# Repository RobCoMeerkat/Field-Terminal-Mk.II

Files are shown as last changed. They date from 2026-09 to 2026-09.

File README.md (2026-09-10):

# RobCo Field Terminal MkII

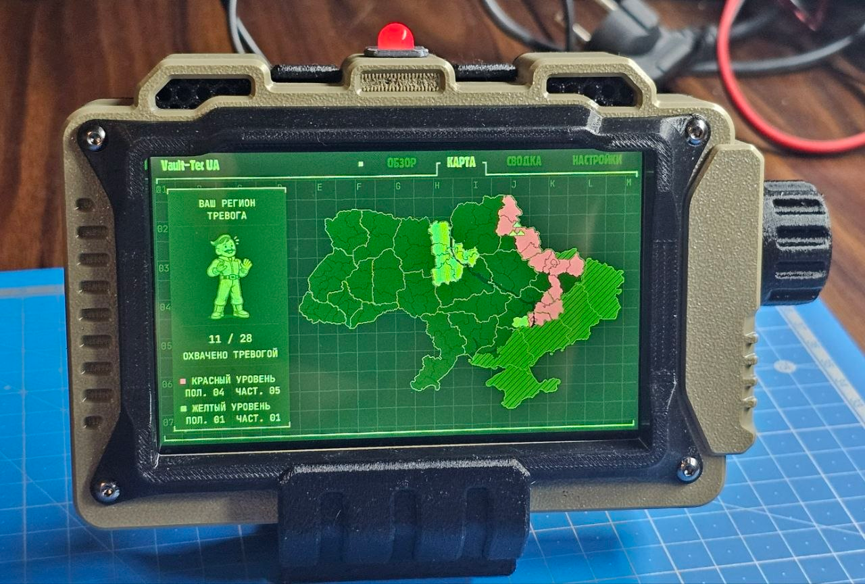
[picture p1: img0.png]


> [!NOTE]
>
> * **Происхождение проекта:** Изначально "терминал" задумывался как настольное устройство с условно полезным функционалом. Т.е. формально игрушка для рабочего стола сделанная на коленке из того что было, ничего серьезного. Проект разрабатывался исключительно для личного использования и был ориентирован на мои собственные потребности.
> * **Доступность сервера:** Серверная часть проекта поддерживается за счёт личных средств. Сервер будет поддерживаться максимально долго по мере возможности, однако в текущих реалиях **гарантии стабильной работы и доступности сервера не предоставляется**.
> * **Точность данных и возможные сбои:** Система использует сторонние API и внешние источники данных, получение информации из которых в отдельных случаях реализовано нестандартными способами(т.е. костылями). Поэтому возможны задержки, временная недоступность отдельных функций и ошибки, не зависящие от меня. **Ответственность за актуальность, точность и своевременность отображаемой информации на себя не беру.**
> * **Обратная связь:** Сообщения об ошибках, конструктивные предложения и идеи по улучшению проекта приветствуются.

---

## 1. Необходимые компоненты

### Электроника

* Отладочная плата **ESP32-8048S050C** в сенсорном исполнении, с экраном 5 дюймов, разрешение 800×480.
  ([Заказывал здесь](https://www.aliexpress.com/item/1005006625220768.html))
* Модуль энкодера **KY-040 (EC11 с резьбой)** — стандартный модуль с пятью выводами: CLK, DT, SW, + и GND.
  ([Пример используемого модуля](https://arduino.ua/ru/prod1223-modyl-enkoder))
* Разъём **USB Type-C "мама"**.
  ([Пример используемого разъёма](https://www.aliexpress.com/item/1005006099544502.html))
* Красный светодиод 8 мм для индикации тревоги.
* Резистор **330 Ом**.
* Соединительные провода и коннекторы.
* USB-кабель для подключения платы к компьютеру (поставляется в комплекте с платой).

### Крепёж и детали корпуса

* Винты M3х24 мм с гайками — 4 шт.
* Винты M2х8 мм с гайками — 2 шт.
* Резиновые кольца или прокладки — 4 шт.
* Детали корпуса, напечатанные на 3D-принтере из PETG пластика.

### Программное обеспечение и драйвер

* [Драйвер USB-SERIAL CH340](https://www.wch-ic.com/downloads/CH341SER_EXE.html)
* [esptool v5.4.0](https://github.com/espressif/esptool/releases/download/v5.4.0/esptool-v5.4.0-windows-amd64.zip)

### Дополнительно

* Немного суперклея.

---

## 2. Первая прошивка

### 2.1. Подготовка

1. Установить драйвер **CH340** и перезагрузить компьютер.
2. Создать в корне диска, например `C:`, отдельную папку для прошивки. Для примера будем использовать:

   ```text
   C:\esptool
   ```
3. Распаковать скачанный архив **esptool** в созданную папку.
4. [Скачайть готовую прошивку](https://github.com/RobCoMeerkat/Field-Terminal-Mk.II/releases/download/test/RobCoFieldTerminal_MkII_V1.5.0_FULL_FACTORY_16MB.bin) и поместить файл `.bin` в ту же папку, рядом с `esptool.exe`.
5. Подключить плату к компьютеру через **USB-порт непосредственно на самой плате**.

---

### 2.2. Определение COM-порта

1. Открыть командную строку Windows:

   * нажать **Win + R**;
   * ввести `cmd`;
   * нажать **Enter**.

2. Перейти в папку, где находятся `esptool.exe` и файл прошивки:

   ```cmd
   cd C:\esptool
   ```

   Если использовали другое расположение папки, указать соответствующий путь.

3. Выполнить команду:

   ```cmd
   esptool flash-id
   ```

4. Дождаться появления информации об обнаруженном устройстве. Найти строку вида:

   ```text
   Connected to ESP32-S3 on COM9
   ```

   В моем случае устройство находится на порту **COM9**.

   **Запомнить номер COM-порта.** В дальнейшем вместо `COM9` необходимо использовать порт, который определился именно на вашем компьютере.

---

### 2.3. Очистка памяти

Перед первой прошивкой рекомендуется полностью удалить заводскую прошивку и содержимое памяти.

Выполнить команду, заменив `COM9` на свой COM-порт:

```cmd
esptool --chip esp32s3 --port COM9 erase-flash
```

Дождаться завершения операции.

При успешном выполнении в конце должен появиться результат примерно следующего вида:

```text
Flash memory erased successfully in XX seconds.
```

---

### 2.4. Прошивка устройства

После очистки памяти можно записать новую прошивку.

Выполнить команду, заменив:

* `COM9` — на COM-порт вашего устройства;
* `RobCoFieldTerminal_MkII_V1.5.0_FULL_FACTORY_16MB.bin` — на фактическое имя файла прошивки, если оно отличается.

```cmd
esptool --chip esp32s3 --port COM9 --baud 230400 write-flash 0x0 RobCoFieldTerminal_MkII_V1.5.0_FULL_FACTORY_16MB.bin
```

Дождаться полного завершения процесса.

Если прошивка выполнена успешно, устройство автоматически запустится.

---

## 3. Первоначальная настройка

После запуска дождитесь появления **QR-кода на экране терминала**.

1. Отсканируйте QR-код телефоном.

2. Подключитесь к Wi-Fi сети, которую создаёт терминал.

3. Откройте в браузере адрес:

   ```text
   192.168.4.1
   ```

4. Откроется веб-панель терминала(нужно подождать, может долго грузиться).

5. Выполните первоначальную настройку устройства.

6. Можно отключаться от компьютера и переходить к сборке.

---

## 4. Сборка

### 4.1. Подключение светодиода:
```
IO17 → резистор 330 Ом → анод LED
GND  → катод LED
```

### 4.2. Подключение энкодера:
```
CLK → IO11
DT  → IO12
SW  → IO13
+   → 3.3V
GND → GND
```

### 4.3. Подключение заднего USB порта:
```
+ (Красный) → 5V
GND(Черный) → GND
```
#### Пример колхозного подключения:
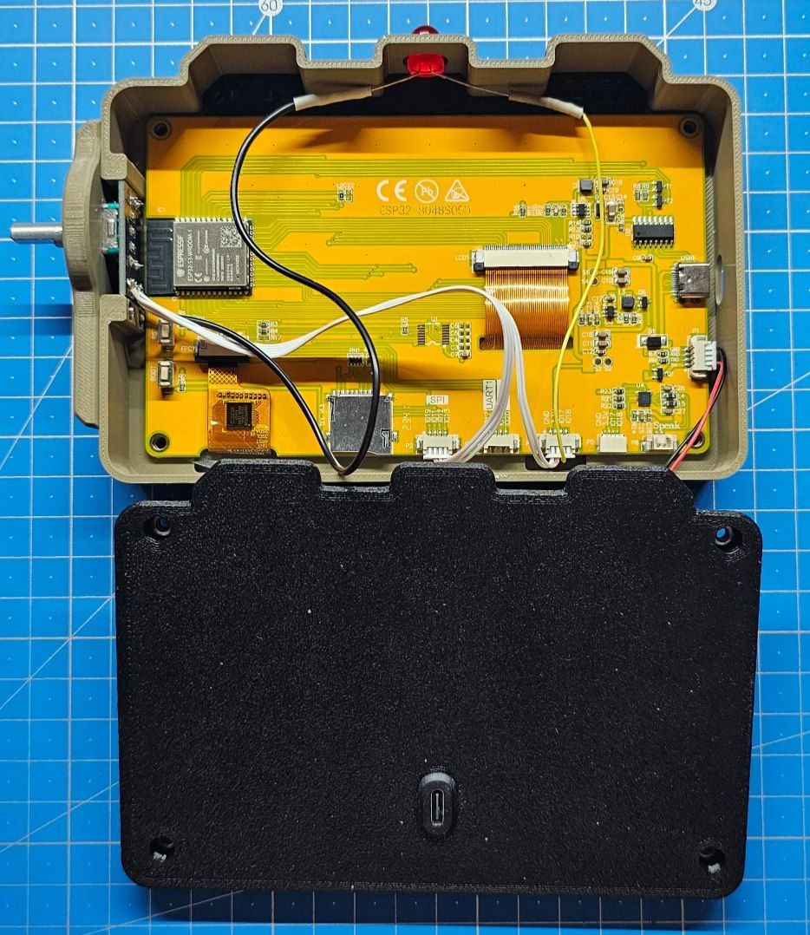
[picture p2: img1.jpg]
Пример колхозного подключения


### 4.4. Финальная сборка

> [!NOTE]
> Корпус может иметь небольшие погрешности печати(Допуски подгонял под печать на моем принтере), но сборка проходит без фатальных сложностей.

#### 1. Подготовка корпуса и закладной крепёж
1. **Вклеивание деталей:** Вклейте суперклеем рамку светодиода и решётку.
2. **Установка гаек:**
   * Заложите гайки **М3** в заднюю крышку.
   * Заложите гайки **М2** в боковую стенку (под крепление панельки энкодера).

#### 2. Монтаж органов управления и разъёмов
1. **Боковая панель:** Прикрутите панельку винтами **М2**.
2. **Разъём USB:** Установите USB-разъём в посадочное место и выполните подключение.
3. **Энкодер:** Вставьте энкодер в боковую панель и затяните комплектной гайкой.
4. **Светодиод:** Вставьте светодиод до упора в верхнюю рамку изнутри. Отверстие сделано чуть меньше диаметра — светодиод входит туго и не требует дополнительной фиксации.

#### 3. Установка экрана и стяжка корпуса
1. С фронтальной стороны корпуса установите рамку экрана и проденьте сквозь неё длинные винты **М3х24**.
2. Переверните корпус и установите плату с экраном на место.
3. Надейте на винты **втулки** и **демпферные резиновые колечки** (можно заменить любым мягким материалом) для безопасного и мягкого прижима платы.

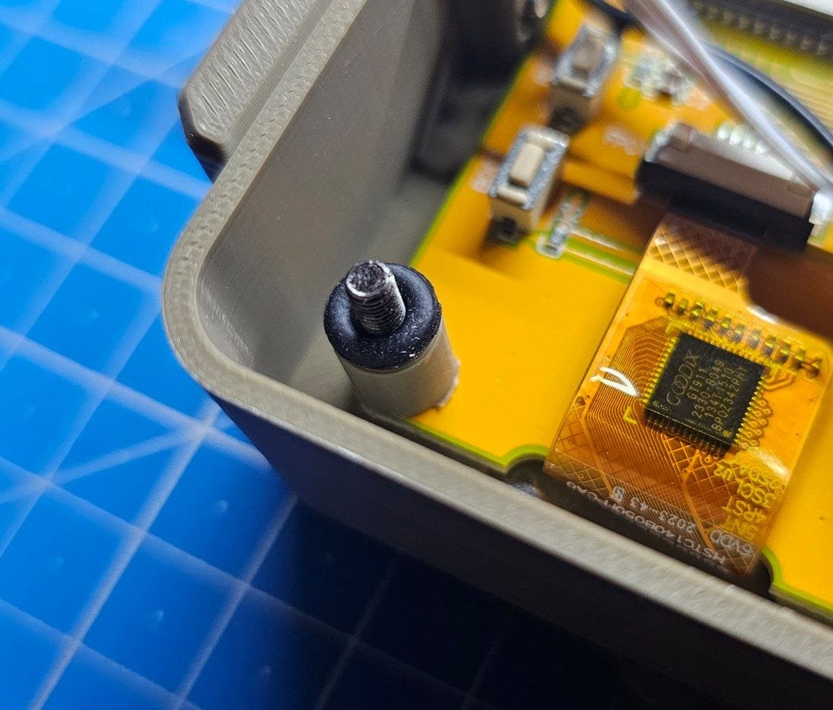
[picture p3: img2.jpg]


4. Накройте корпус задней крышкой и затяните винты с фронтальной стороны, равномерно стягивая все части.
5. Наденьте колпачок на вал энкодера.
6. Установите собранное устройство в подставку.

Теперь можно подключать к компьютеру/павербанку и использовать. Дополнительный USB порт специально вынес на заднюю крышку, чтоб можно было аккуратно протянуть провод питания.

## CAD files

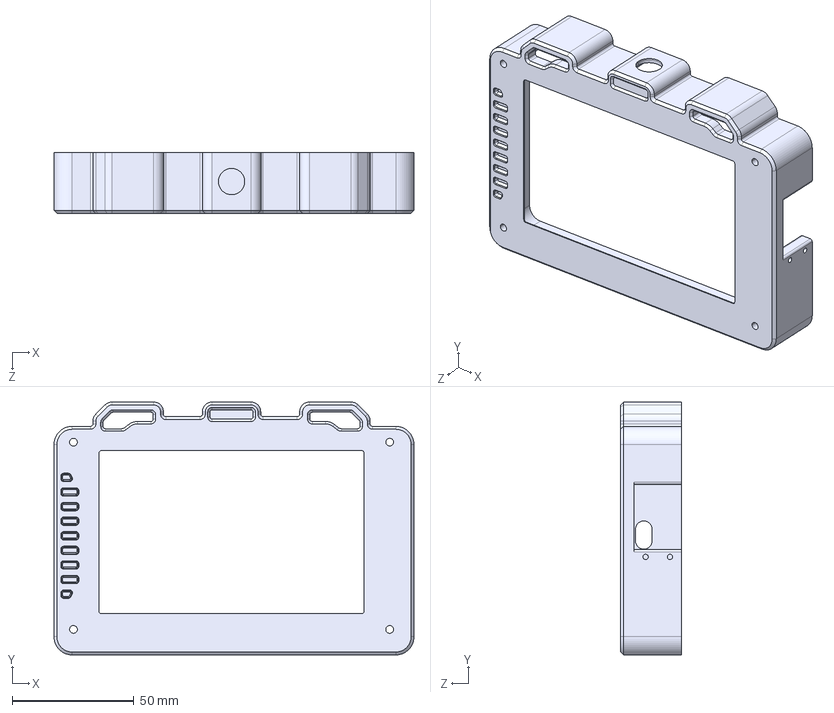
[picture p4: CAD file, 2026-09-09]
STEP/Основа.STEP
148.0 x 104.0 x 25.0 mm

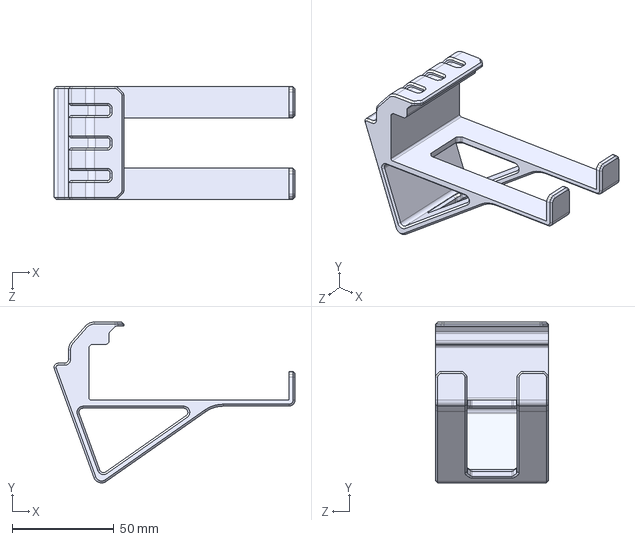
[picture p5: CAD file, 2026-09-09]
STEP/Подставка.STEP
118.6 x 79.2 x 55.6 mm

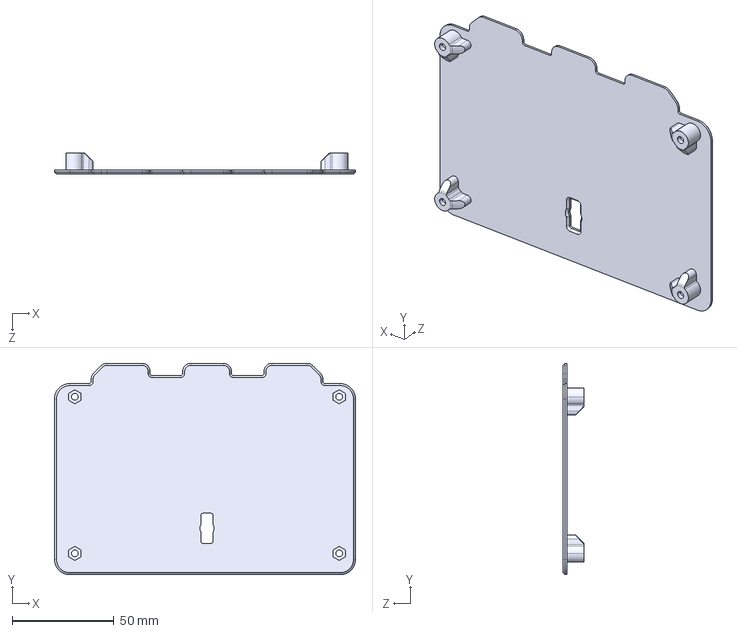
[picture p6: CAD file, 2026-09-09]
STEP/Задняя_Крышка.STEP
148.0 x 104.0 x 10.5 mm

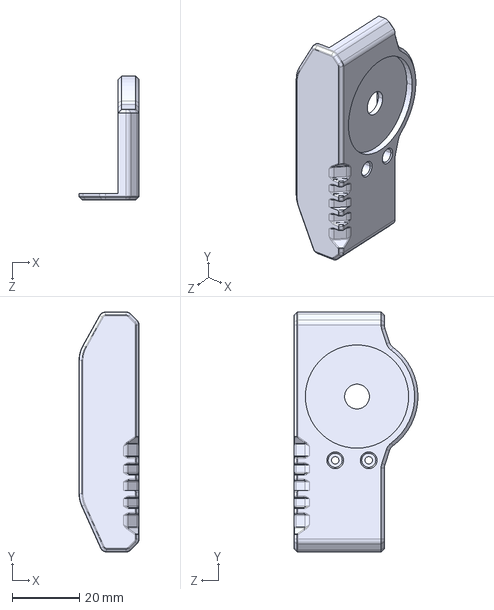
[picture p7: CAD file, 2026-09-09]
STEP/Крепление_Энкодера.STEP
17.9 x 71.6 x 37.0 mm

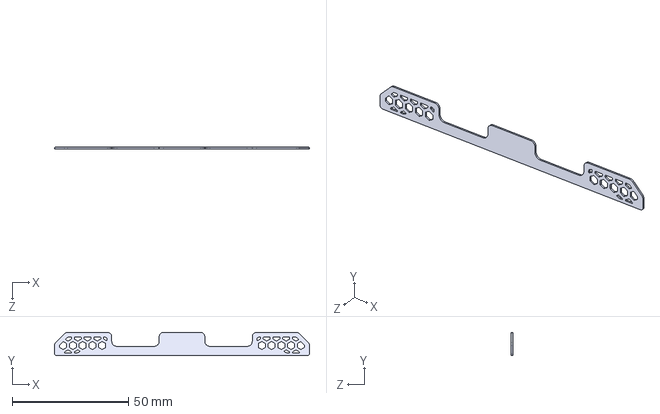
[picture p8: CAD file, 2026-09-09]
STEP/РешеткаSLDPRT.STEP
109.6 x 9.99 x 0.8 mm

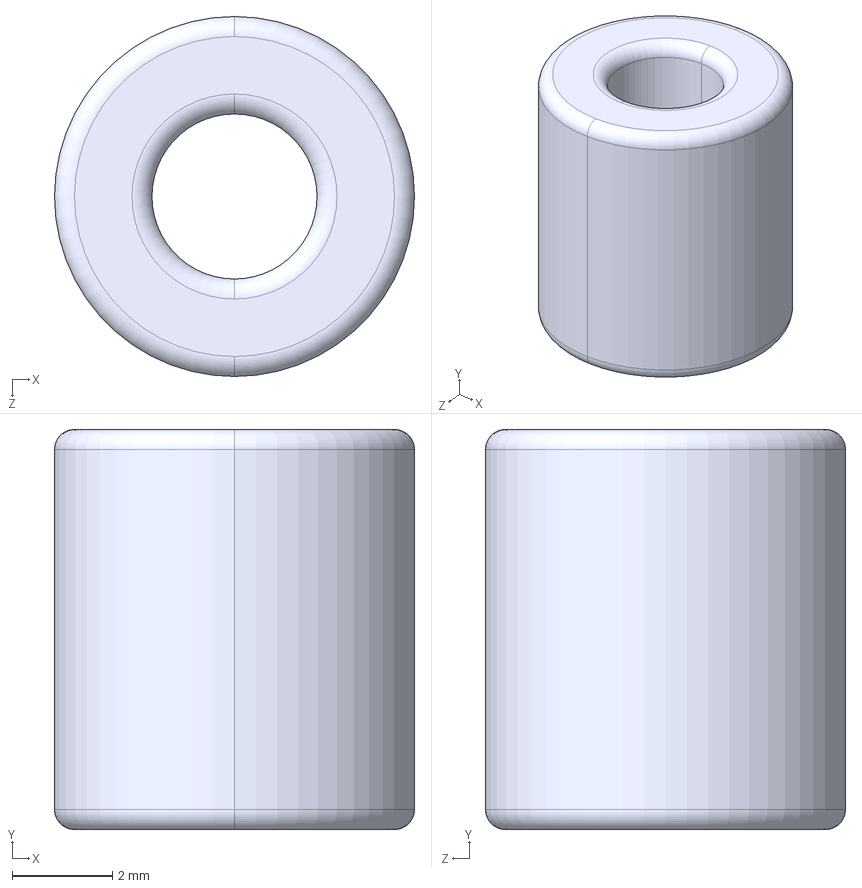
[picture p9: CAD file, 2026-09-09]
STEP/Втулка.STEP
7.20 x 8.00 x 7.20 mm

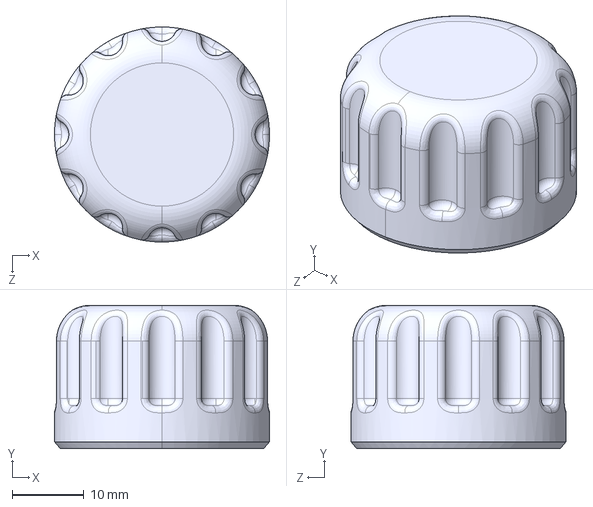
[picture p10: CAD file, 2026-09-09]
STEP/Колпачок_Энкодера.STEP
30.0 x 20.0 x 30.0 mm

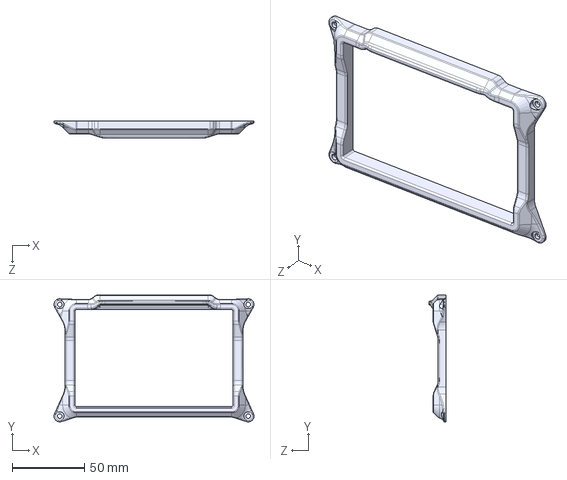
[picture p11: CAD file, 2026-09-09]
STEP/Рамка.STEP
138.0 x 87.5 x 12.0 mm

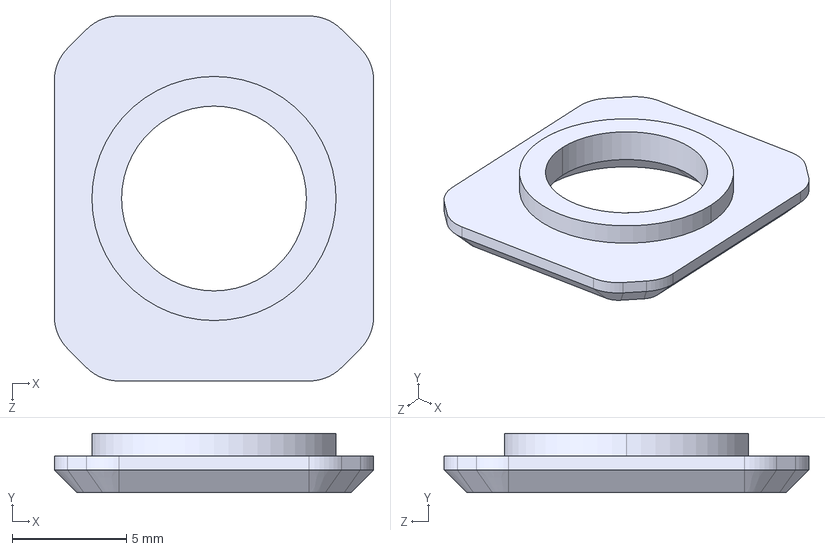
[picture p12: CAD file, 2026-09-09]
STEP/Рамка_Светодиода.STEP
14.0 x 2.60 x 16.0 mm
